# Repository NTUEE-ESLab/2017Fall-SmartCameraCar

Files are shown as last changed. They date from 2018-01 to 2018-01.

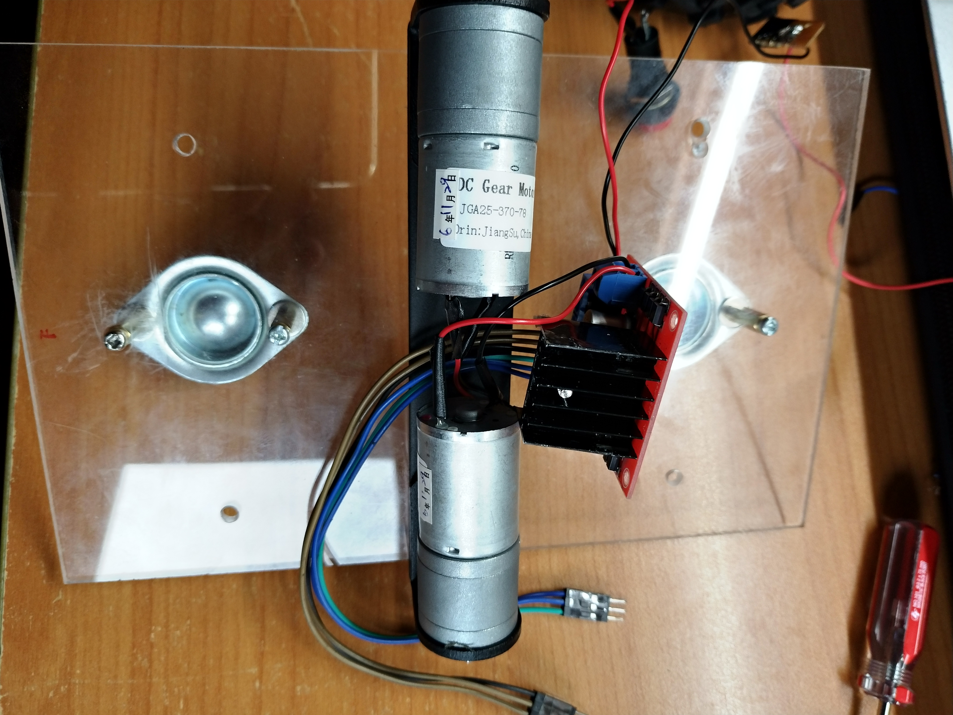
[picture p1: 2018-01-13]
webpage/images/step5.jpg

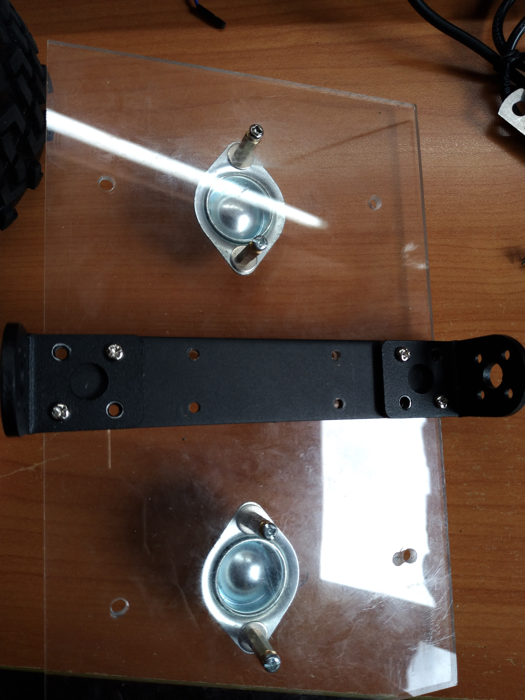
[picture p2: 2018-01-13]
webpage/images/step3.jpg

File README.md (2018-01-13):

# Smart Camera Car

>2017 Fall NTUEE ESlab final project  
>group members:  
>b03901004  
>b03901162 

## Menu
* [Webpage](https://ntuee-eslab.github.io/2017Fall-SmartCameraCar/webpage/index.html)
* [Introduction](https://github.com/NTUEE-ESLab/2017Fall-SmartCameraCar#introduction)
* [Motivation](https://github.com/NTUEE-ESLab/2017Fall-SmartCameraCar#motivation)
* [Requirements](https://github.com/NTUEE-ESLab/2017Fall-SmartCameraCar#requirements)
* [Before use the code](https://github.com/NTUEE-ESLab/2017Fall-SmartCameraCar#before-use-the-code)
* [Usage](https://github.com/NTUEE-ESLab/2017Fall-SmartCameraCar#usage)
* [Result](https://github.com/NTUEE-ESLab/2017Fall-SmartCameraCar#result)
* [Reference](https://github.com/NTUEE-ESLab/2017Fall-SmartCameraCar#reference)

## Introduction
This is a small camera car that can follow your motion and shot video for you.

## Motivation
If you want to make a third-person video of yourself, but there are no helpers, and you don't have a good device, like a drone, to do that for you, how will you get it done?  
We want to build a device to help we shot high quality, smooth videos.
It should carry your own device, like cellphones or cameras, to ensure the video quality.  
It should to be cheap.  
Then we built this Smart Camera Car, everybody can use it.  

## Requirements

### Hardwares
- Raspberry pi 3 (Model B), with micro sd card larger than 16GB
- Raspberry pi camera module with cable longer than 30cm
- Arduino uno
- L298N
- 2 motors(JGA25-371) and wheels
- 2 universal wheels
- Tower Pro SG-90 servo motor
- 2 output Powerbank (we use asus zenpower pro)
- 8 AA battery and a battery box
- car body (how to design it is up to you)
- [thrust bearing(skf 51305)](/webpage/images/thrust_bearing.jpg)

### Softwares
- C++
- python3
- OpenCV
- darknet-nnpack

## Before use the code

This Project contain 2 main devices, Raspberry pi and Arduino.  There are some preparation you should do before use it.

### For Raspberry pi:  

### Install [OpenCV](https://opencv.org/)

This is used for target detection and tracking.

You should install OpenCV on the Raspberry pi  

Intsall cmake and some other tools

```bash
sudo apt-get install build-essential cmake pkg-config  
sudo apt-get install libjpeg-dev libtiff5-dev libjasper-dev libpng12-dev  
sudo apt-get install libavcodec-dev libavformat-dev libswscale-dev libv4l-dev  
sudo apt-get install libxvidcore-dev libx264-dev  
sudo apt-get install libgtk2.0-dev  
sudo apt-get install libatlas-base-dev gfortran
```

Then clone OpenCV and contrib repository.  cd to a directory, and 

```bash
git clone https://github.com/opencv/opencv.git  
git clone https://github.com/opencv/opencv_contrib.git
```

Then make a build directory and get into it, for example:

```bash
cd opencv  
mkdir build  
cd build
```

Then use cmake to prepare the files

```bash
cmake -D CMAKE_BUILD_TYPE=RELEASE -D CMAKE_INSTALL_PREFIX=/usr/local  -D INSTALL_PYTHON_EXAMPLES=ON -D OPENCV_EXTRA_MODULES_PATH=<opencv_contrib folder>/modules <opencv folder>
```

Then compile it, use `-j4` to use 4 core of Raspberry pi.  It may takes more than 2 hours, depends on the speed of micro sd card.

```bash 	simple_servo_test.ino
make -j4
```

After compile, install it

```bash
sudo make install  
sudo ldconfig
```

Then install is finish.  To save the space, you can remove the source code folders.

```bash
sudo rm -rf opencv opencv_contrib
```

### Install [Darknet-NNPACK](https://github.com/digitalbrain79/darknet-nnpack)

This is used for detect target recognition.

You need to install PeachPy and confu

```bash
sudo pip install --upgrade git+https://github.com/Maratyszcza/PeachPy  
sudo pip install --upgrade git+https://github.com/Maratyszcza/confu  
```

Also you need to install Ninja

```bash
git clone https://github.com/ninja-build/ninja.git  
cd ninja  
git checkout release  
./configure.py --bootstrap  
export NINJA_PATH=$PWD  
```

Install clang

```bash
sudo apt-get install clang  
```

Install NNPACK-darknet

```bash
git clone https://github.com/thomaspark-pkj/NNPACK-darknet.git  
cd NNPACK-darknet  
confu setup  
python ./configure.py --backend auto  
$NINJA_PATH/ninja  
sudo cp -a lib/* /usr/lib/  
sudo cp include/nnpack.h /usr/include/  
sudo cp deps/pthreadpool/include/pthreadpool.h /usr/include/  
```

Build darknet-nnpack

```bash
git clone https://github.com/thomaspark-pkj/darknet-nnpack.git  
cd darknet-nnpack  
```

Then edit the Makefile to build darknet-nnpack for opencv

```bash
vim Makefile  
```

Edit the 3rd line of the makefile

```
OPENCV=1  
```

Then make it

```bash
make  
```

### Install flask

This is used for sending video stream to webpage.

```bash
sudo pip3 install Flask  
```

### Enable camera

Insert the camra module onto Raspberry pi.  

Enable the camera

```bash
sudo raspi-config
```

Then reboot the pi.

After rebooting, you can use `vcgencmd get_camera` to check if the camera is available.  You should see the text below:

```bash
supported=1 detected=1
```

For OpenCV to use the camera, we should enable v4l2 (the script `enable_v4l2.sh` can do the same thing) (you should do this all the time, so we recommend you to add it into `~/.bashrc`)

```bash
sudo modprobe bcm2835-v4l2
```

Then you can see the camera device at `/dev/video0`, and you can use `VideoCapture video(0);` to get the camera frames.

### Enable I2C

Enable the I2C

```bash
sudo raspi-config
```

Then reboot the pi.

Install I2C tool

```bash
sudo apt-get install i2c-tools
```

### For Arduino:  
Use Arduino IDE to upload the code in Base_motor_and_Plat_motor_controller/ into Arduino.  
[Base_motor_and_Plat_motor_controller.ino](https://github.com/NTUEE-ESLab/2017Fall-SmartCameraCar/blob/master/Base_motor_and_Plat_motor_controller/Base_motor_and_Plat_motor_controller.ino)

We also provide some simple test program for motor, L298N and servo.  
[Simple_motor_andL298N_test.ino](https://github.com/NTUEE-ESLab/2017Fall-SmartCameraCar/blob/master/Base_motor_and_Plat_motor_controller/simple_motor_andL298N_test.ino)
[Simple_servo_test.ino](https://github.com/NTUEE-ESLab/2017Fall-SmartCameraCar/blob/master/Base_motor_and_Plat_motor_controller/simple_servo_test.ino)

### Build the car
Please refer to the [webpage](https://ntuee-eslab.github.io/2017Fall-SmartCameraCar/webpage/build.html).  

## Usage
After setup the whole car, turn on Arduino, Raspberry pi and the whole power.  
On Raspberry pi, you should run 2 programs.  
The `myapp_opencv.py` setup a server for webpage monitering.  
The `Tracker_and_I2C` is the main tracking program.  
  
Simple type `make` to compile `Tracker_and_I2C.cpp`, then you can start track  

```bash
cd RPi_programs  
python3 myapp_opencv.py &  
./Tracker_and_I2C  
```

After run the programs, stay in front of the camera for a while, and the car will automatically start tracking you.  
You can use devices connected to the same LAN as RPi, and use web browser to `<RPi IP>:5000`, and you can moniter the car.  

### Note:

If the tracking fail, press `esc` key to terminate the program.  
If you kill the program directly, the car may still runing.  Then run the `hardstop` program to stop it.  
If you see `Address already in use` error while use `myapp_opencv.py`, then follow the steps below:  

- If you don't have `lsof`, then install it by typing `sudo apt-get install lsof`. Use `lsof -i:5000` to find the program using the port 5000, and you can see the python PID, then `kill <python PID>`, and you can open `myapp_opencv.py` again.  

## Result
Please see the [webpage](https://ntuee-eslab.github.io/2017Fall-SmartCameraCar/webpage/index.html).  

## Reference
Please see the [webpage](https://ntuee-eslab.github.io/2017Fall-SmartCameraCar/webpage/reference.html).

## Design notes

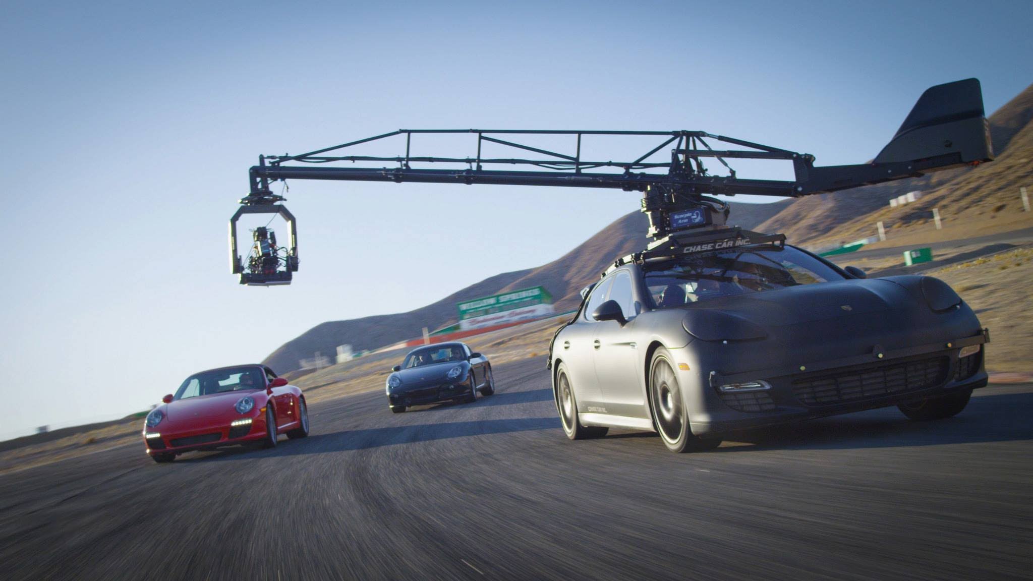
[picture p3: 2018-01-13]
webpage/images/bg.jpg

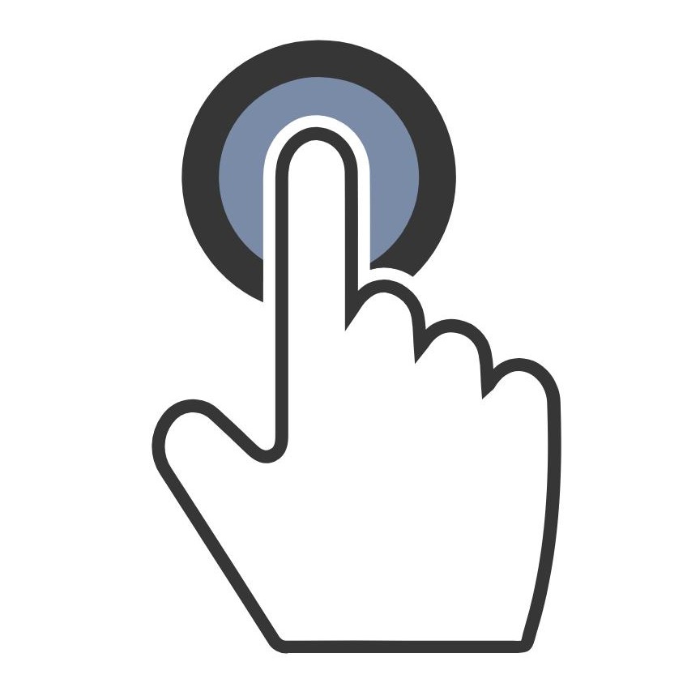
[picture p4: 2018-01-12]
webpage/images/easy.jpg

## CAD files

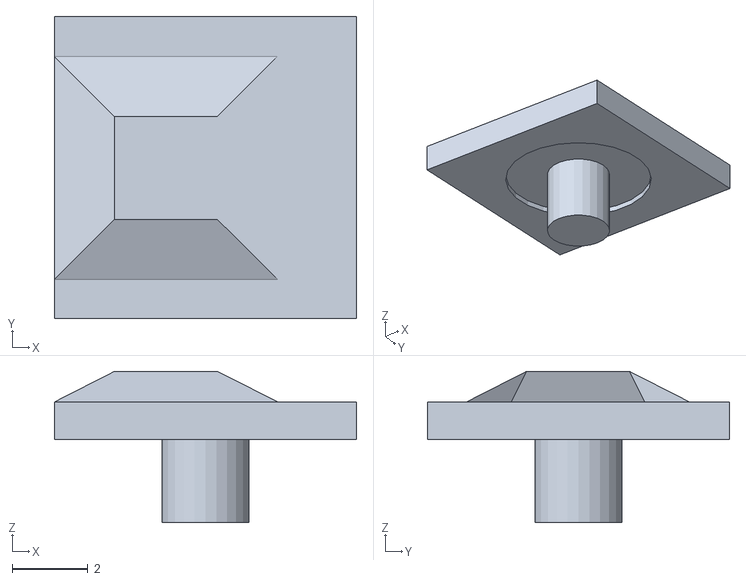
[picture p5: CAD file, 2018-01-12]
car_body_3d_model/car_top.stl
8.00 x 8.00 x 4.01

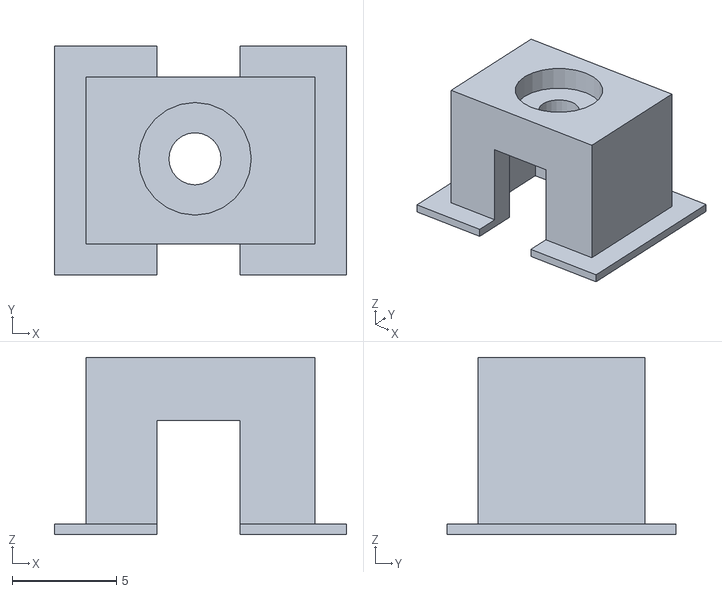
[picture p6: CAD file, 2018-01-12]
car_body_3d_model/car_button.stl
14.0 x 11.0 x 8.50

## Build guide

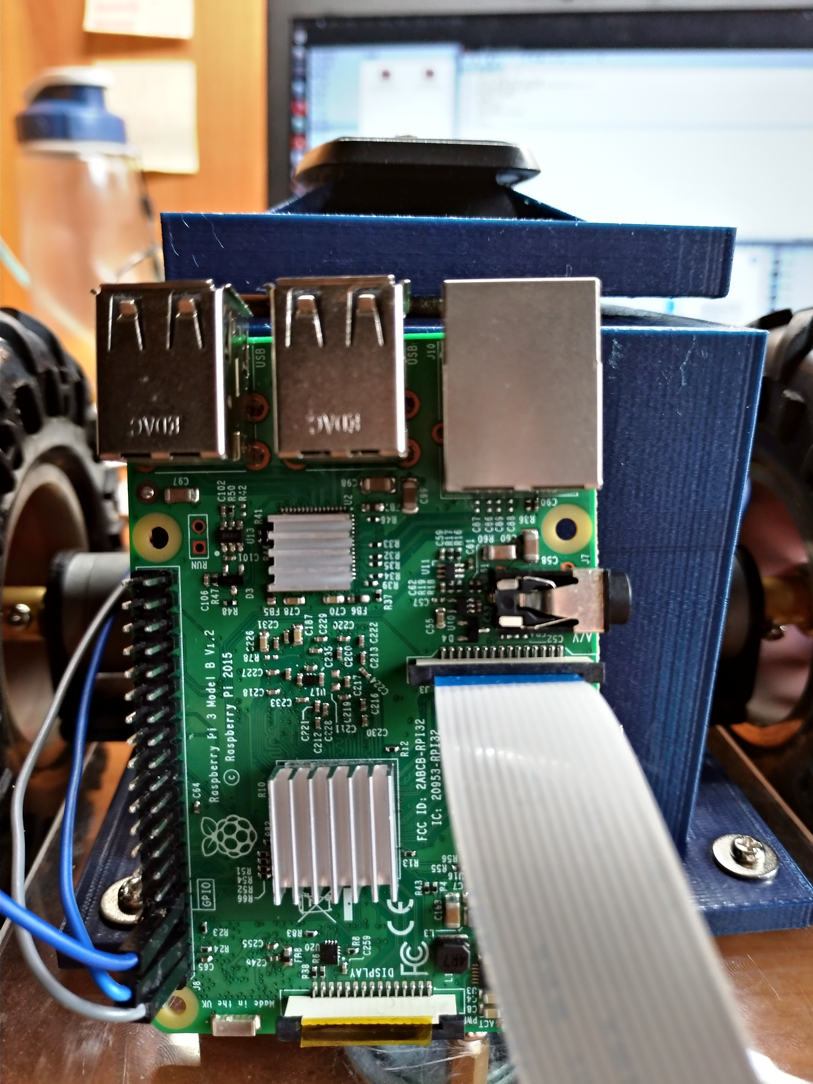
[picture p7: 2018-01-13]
webpage/images/step14.jpg

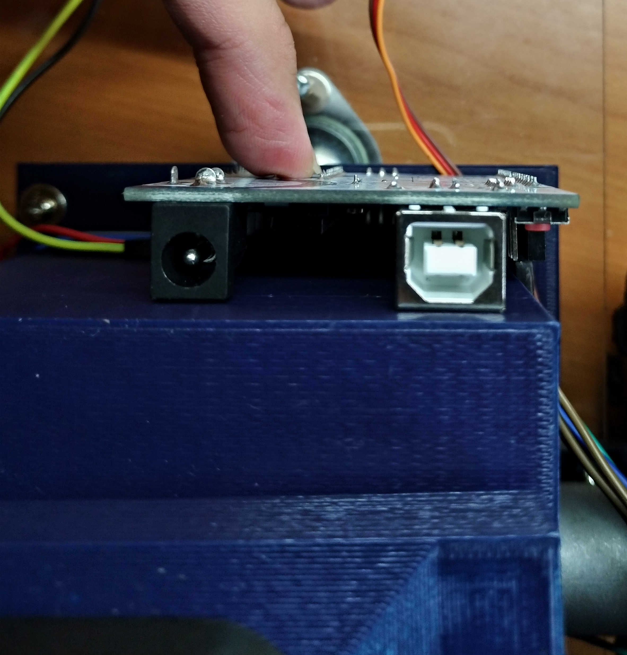
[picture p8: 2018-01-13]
webpage/images/step12.jpg

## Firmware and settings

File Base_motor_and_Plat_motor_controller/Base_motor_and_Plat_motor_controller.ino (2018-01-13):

#include <Wire.h>
#include <Servo.h>
#include <PID_v1.h>

#define SLAVE_ADDRESS 0x04

//I2C input
int input[3];
int inputDirection = 0;
int inputVerticalSpeed = 0;
int inputHorizontalSpeed = 0;
int inputCount = 0;
int inputMode = 0;
int forward_backward = 0;
int right_left = 0;
bool first = true;

//L298n
// motor one
int enA = 11;
int in1 = 10;
int in2 = 9;
// motor two
int in3 = 7;
int in4 = 6;
int enB = 5;

//servo
Servo myservo;

//Define Variables we'll be connecting to
//double Setpoint, Input, Output;
//float Kp = 0.5;
//float Ki = 0.0;
//float Kd = 0.0;

//PID
//PID myPID(&Input, &Output, &Setpoint, Kp, Ki, Kd, DIRECT);;

//parameters
//motor
int minmoveSpeed = 140;
int moveSpeed = 140;
int minrotateSpeed = 90;
int rotateSpeed = 110;
int deltaSpeed = 10;
int SurroundmoveSpeed = 120;
int SurrounddeltaSpeed = 70;
//threshold
int verticalThreshold = 100;
int horizontalThreshold = 100;

//servo
int degree = 100;
int servoSpeed = 100;



void setup()
{
  // 車體馬達
  pinMode(enA, OUTPUT);
  pinMode(enB, OUTPUT);
  pinMode(in1, OUTPUT);
  pinMode(in2, OUTPUT);
  pinMode(in3, OUTPUT);
  pinMode(in4, OUTPUT);

  // I2C to RPi
  pinMode(13, OUTPUT);
  Serial.begin(9600);
  Wire.begin(SLAVE_ADDRESS);
  Wire.onReceive(receiveData);

  // 雲台馬達
  myservo.attach(12);
  
  //pid
  //Setpoint = 0;  //dont care in our case
  //Input = 0;
  //myPID.SetMode(AUTOMATIC);
}

// callback for received data
void receiveData(int byteCount){
  while(Wire.available()) {
    int inputData = Wire.read();
    //Serial.print(inputCount);
    //Serial.print(' ');
    //Serial.print(inputData);
    //Serial.println();
    
    if (inputData == 255)
    {
      inputCount = 0;
    }
    input[inputCount] = inputData;
    inputCount++;
    if (inputCount == 4)
    {
      inputCount = 0;
      inputDirection = input[1];
      inputVerticalSpeed = input[2];
      inputHorizontalSpeed = input[3];
      inputMode = (inputDirection)/9;
      forward_backward = ((inputDirection)/3)%3;
      right_left = (inputDirection)%3;
      first = true;
    }
  }
}
void hardstop()
{
  digitalWrite(in1, LOW);
  digitalWrite(in2, LOW);
  digitalWrite(in3, LOW);
  digitalWrite(in4, LOW);
  analogWrite(enA, 0);
  analogWrite(enB, 0);
}
void backward()
{
  digitalWrite(in1, LOW);
  digitalWrite(in2, HIGH);
  digitalWrite(in3, LOW);
  digitalWrite(in4, HIGH);
  analogWrite(enA, moveSpeed-deltaSpeed);
  analogWrite(enB, moveSpeed);
}
void forward()
{
  digitalWrite(in1, HIGH);
  digitalWrite(in2, LOW);
  digitalWrite(in3, HIGH);
  digitalWrite(in4, LOW);
  analogWrite(enA, moveSpeed-deltaSpeed);
  analogWrite(enB, moveSpeed);
}
void left()
{
  digitalWrite(in1, LOW);
  digitalWrite(in2, HIGH);
  digitalWrite(in3, HIGH);
  digitalWrite(in4, LOW);
  analogWrite(enA, rotateSpeed);
  analogWrite(enB, rotateSpeed);
}
void right()
{
  digitalWrite(in1, HIGH);
  digitalWrite(in2, LOW);
  digitalWrite(in3, LOW);
  digitalWrite(in4, HIGH);
  analogWrite(enA, rotateSpeed);
  analogWrite(enB, rotateSpeed);
}
void surround ()
{
  digitalWrite(in1, HIGH);
  digitalWrite(in2, LOW);
  analogWrite(enA, moveSpeed-deltaSpeed);
  digitalWrite(in3, HIGH);
  digitalWrite(in4, LOW);
  analogWrite(enB, moveSpeed+SurrounddeltaSpeed);
}
void loop()
{
  if (inputMode == 0) // follow mode
  {
    myservo.write(98);
    //moveSpeed = (inputVerticalSpeed < verticalThreshold)? minmoveSpeed+(255-minmoveSpeed)*inputVerticalSpeed/verticalThreshold : 255;
    //rotateSpeed = (inputHorizontalSpeed < horizontalThreshold)? minrotateSpeed+(255-minrotateSpeed)*inputHorizontalSpeed/horizontalThreshold : 255;
    //Serial.print(inputDirection);
    //Serial.print(' ');
    //Serial.print(moveSpeed);
    //Serial.print(' ');
    //Serial.print(rotateSpeed);
    //Serial.println();
    
    
    if (right_left == 1)
    {
      if (first)
      {
        for (int i = 0; i < rotateSpeed; ++i)
        {
          analogWrite(enA, i);
          analogWrite(enB, i);
          delay (10);
        }
      }
      first = false;
      left ();
    }
    else if (right_left == 2)
    {
      if (first)
      {
        for (int i = 0; i < rotateSpeed; ++i)
        {
          analogWrite(enA, i);
          analogWrite(enB, i);
          delay (10);
        }
      }
      first = false;
      right ();
    }
    else if (forward_backward == 1)
    {
      forward ();
    }
    else if (forward_backward == 2)
    {
      backward ();
    }
    else
    {
      hardstop();
    }
  }
  else if (inputMode == 1) // surround mode
  {
    
    myservo.write(8);
    //surround();
  }
  else if (inputMode == 2) // 360 mode
  {
    rotateSpeed = minrotateSpeed;
    right ();
  }
  else
  {
    hardstop();
  }
}

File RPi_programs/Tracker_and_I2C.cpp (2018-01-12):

#include <opencv2/opencv.hpp>
#include <opencv2/tracking.hpp>
#include <opencv2/core/ocl.hpp>
#include <opencv2/core/utility.hpp>
#include <opencv2/videoio.hpp>
#include <opencv2/highgui.hpp>
#include <opencv2/dnn.hpp>
#include <opencv2/dnn/shape_utils.hpp>
#include <opencv2/imgproc.hpp>
#include <iostream>
#include <cstring>
#include <fstream>
#include <algorithm>
#include <cstdlib>
// #include <boost/asio.hpp>

// the i2c dependencies
#include <unistd.h>
#include <fcntl.h>
#include <sys/ioctl.h>
#include <linux/i2c-dev.h>

using namespace cv;
using namespace std;
using namespace cv::dnn;
// using namespace boost::asio;

// Convert to string
#define SSTR( x ) static_cast< std::ostringstream & >( \
( std::ostringstream() << std::dec << x ) ).str()

// The arduino board i2c address (slave)
#define ADDRESS 0x04

// The I2C bus: This is for V2 pi's. For V1 Model B you need i2c-0
static const char *devName = "/dev/i2c-1";

bool Target_Detector(string& TargetClass, Rect2d& bbox, Mat& frame, dnn::Net& net, vector<String>& classNamesVec)
{
    if (frame.channels() == 4)
        cvtColor(frame, frame, COLOR_BGRA2BGR);
    Mat inputBlob = blobFromImage(frame, 1 / 255.F, Size(416, 416), Scalar(), true, false); //Convert Mat to batch of images
    net.setInput(inputBlob, "data");                   //set the network input
    Mat detectionMat = net.forward("detection_out");   //compute output
    // float confidenceThreshold = parser.get<float>("min_confidence");

    bool detected=false;
    float max_condidence=0; // the confidence of detecting certain terget

    for (int i = 0; i < detectionMat.rows; i++)
    {
        const int probability_index = 5;
        const int probability_size = detectionMat.cols - probability_index;
        float *prob_array_ptr = &detectionMat.at<float>(i, probability_index);
        size_t objectClass = max_element(prob_array_ptr, prob_array_ptr + probability_size) - prob_array_ptr;
        float confidence = detectionMat.at<float>(i, (int)objectClass + probability_index);
        // if (confidence > confidenceThreshold)
        if(confidence>0.1)
        {
            float x_center = detectionMat.at<float>(i, 0) * frame.cols;
            float y_center = detectionMat.at<float>(i, 1) * frame.rows;
            float width = detectionMat.at<float>(i, 2) * frame.cols;
            float height = detectionMat.at<float>(i, 3) * frame.rows;
            Point p1(cvRound(x_center - width / 2), cvRound(y_center - height / 2));
            Point p2(cvRound(x_center + width / 2), cvRound(y_center + height / 2));
            Rect object(p1, p2);
            Scalar object_roi_color(0, 255, 0);
            // if (object_roi_style == "box")
            // {
                rectangle(frame, object, object_roi_color);
            // }
            // else
            // {
            //     Point p_center(cvRound(x_center), cvRound(y_center));
            //     line(frame, object.tl(), p_center, object_roi_color, 1);
            // }
            String className = objectClass < classNamesVec.size() ? classNamesVec[objectClass] : cv::format("unknown(%d)", objectClass);
            String label = format("%s: %.2f", className.c_str(), confidence);
            int baseLine = 0;
            Size labelSize = getTextSize(label, FONT_HERSHEY_SIMPLEX, 0.5, 1, &baseLine);
            rectangle(frame, Rect(p1, Size(labelSize.width, labelSize.height + baseLine)),
                      object_roi_color, CV_FILLED);
            putText(frame, label, p1 + Point(0, labelSize.height),
                    FONT_HERSHEY_SIMPLEX, 0.5, Scalar(0,0,0));
            cout<<label<<", x="<<x_center<<", y="<<y_center<<", h="<<height<<", w="<<width<<endl;

            if(className==TargetClass) // choose the init bbox
            {
                detected=true;
                if(confidence>max_condidence)
                {
                    max_condidence=confidence;
                    bbox.x=x_center-width/2;
                    bbox.y=y_center-height/2;
                    bbox.height=height;
                    bbox.width=width;
                }
            }
        }
    }
    imshow("YOLO: Detections", frame);
    imwrite("frame.jpg",frame);
    // while(1) {
    //     if(waitKey(1)==27) break; }
    return detected;
}

bool Write_to_I2C(int& file_i2c,int& Forward_Backward,int& Forward_Backward_Speed,int& Left_Right,int& Left_Right_Speed)
{
    unsigned char buffer[1];
    bool WriteFail = false;

    buffer[0] = 255; // acknowledgement
    if (write(file_i2c, buffer, 1) != 1)
    {
        WriteFail = true;
    }
    
    buffer[0] = Forward_Backward * 3 + Left_Right;
    if (write(file_i2c, buffer, 1) != 1)
    {
        WriteFail = true;
    }

    buffer[0] = Forward_Backward_Speed;
    if (write(file_i2c, buffer, 1) != 1)
    {
        WriteFail = true;
    }
        
    buffer[0] = Left_Right_Speed;
    if (write(file_i2c, buffer, 1) != 1)
    {
        WriteFail = true;
    }

    if (WriteFail)
    {
        cout << "Failed to write to the i2c bus.";
    }
    else
    {
        cout << "                               ";
    }   
}
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

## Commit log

2017-12-27 add i2c-arduino-rpi code
2017-12-27 basically combine the tracker and i2c, untested
2017-12-28 update i2c code from c to c++
2017-12-28 add install i2c tools
2018-01-04 will not move if loss track
2018-01-05 driver bug fixed
2018-01-05 can do baisc track
2018-01-08 pid initial test
2018-01-08 add tiny yolo datas
    [tiny-yolo-voc.cfg]
2018-01-11 tell arduino to stop while loss track. also try to use flask
2018-01-11 fix esc problem
2018-01-11 try on the socket, c++ server, python client, and success
2018-01-11 put the i2c into a function
2018-01-12 add 3d models and edit readme
    [car_button.stl, car_top.stl]
2018-01-13 update arduino code
2018-01-13 add some arduino test
